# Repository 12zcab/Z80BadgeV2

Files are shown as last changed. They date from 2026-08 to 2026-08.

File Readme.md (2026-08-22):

# Z80 Badge V2

## a total redesign of my fallout badge!

## submitted to Gadget@HackClub

# HUGE THXXXX to Cyao and Acon and mpk for suggestions!!!!

### Images

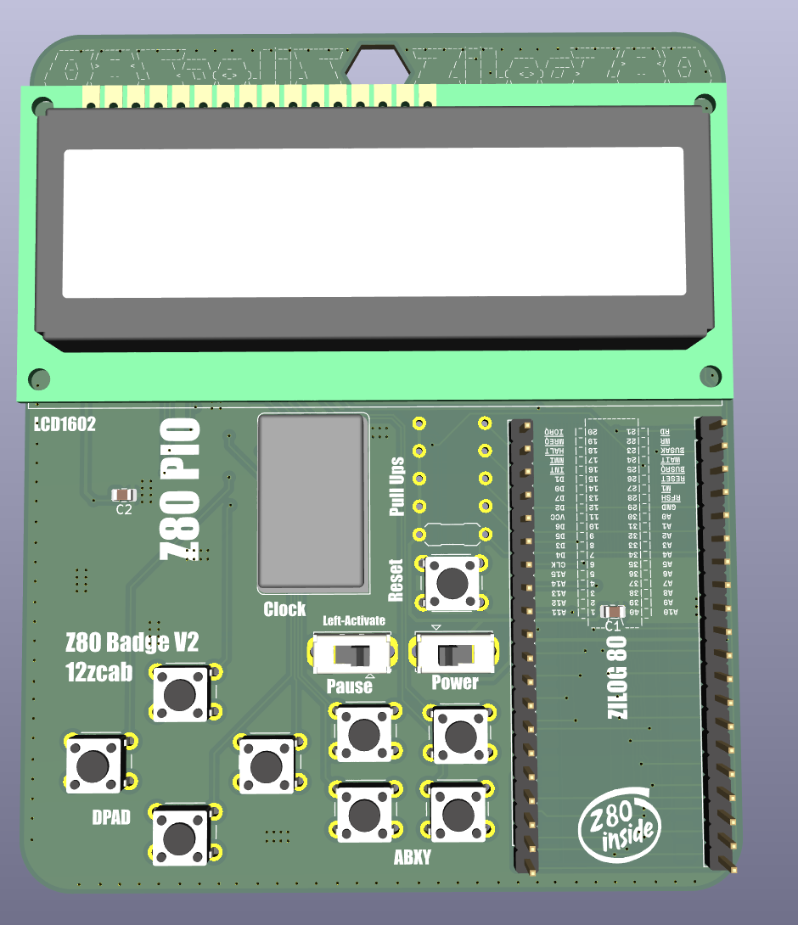
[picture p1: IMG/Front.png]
Front


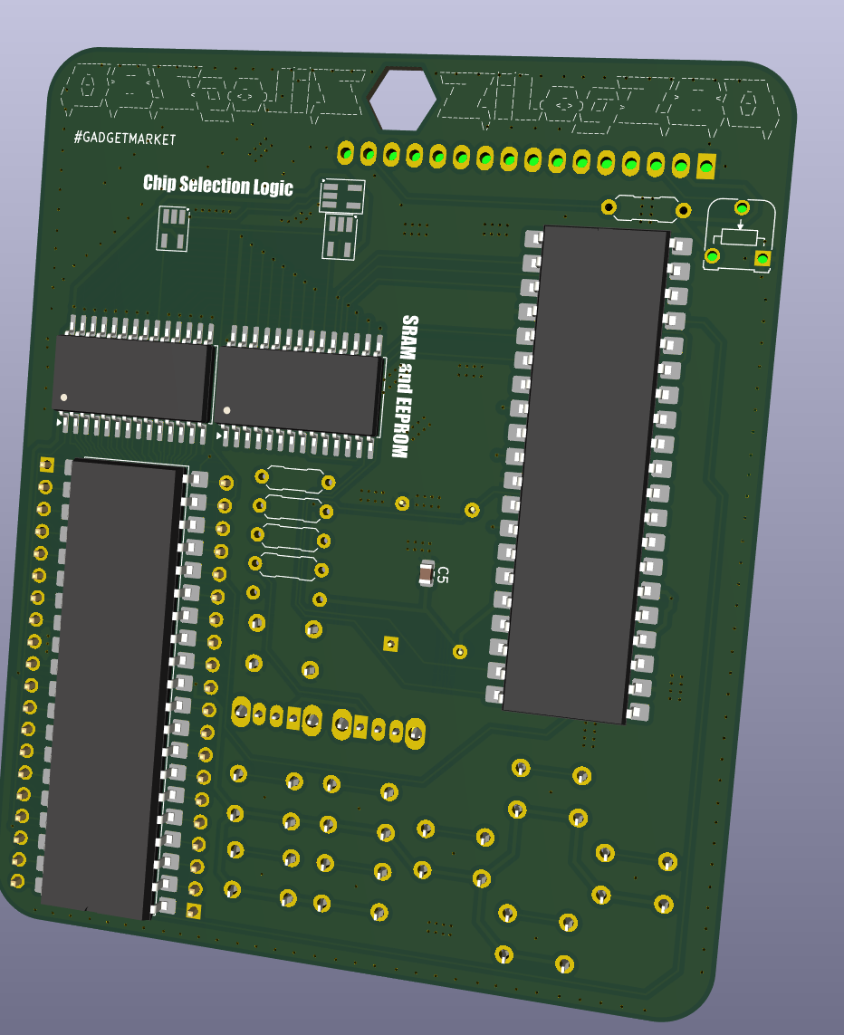
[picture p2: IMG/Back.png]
Back


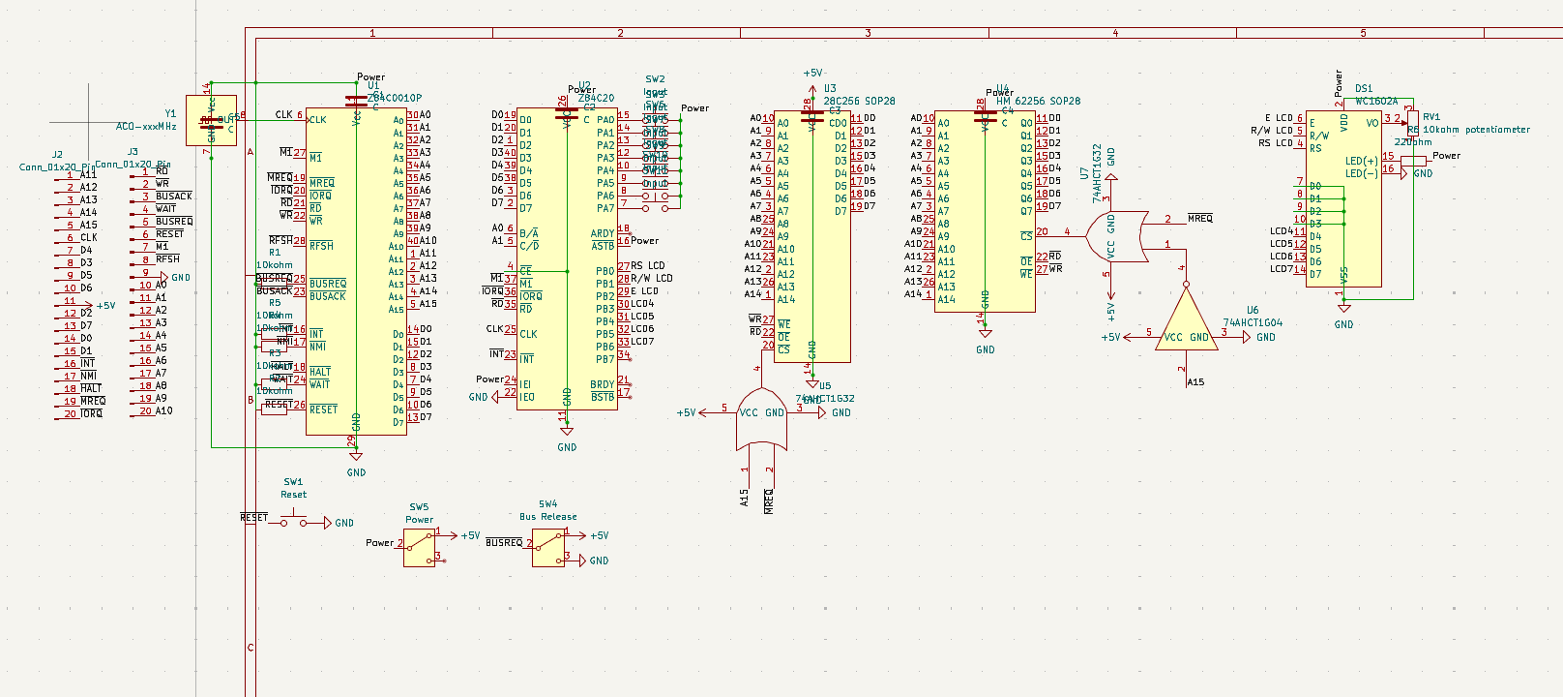
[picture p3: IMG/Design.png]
Design


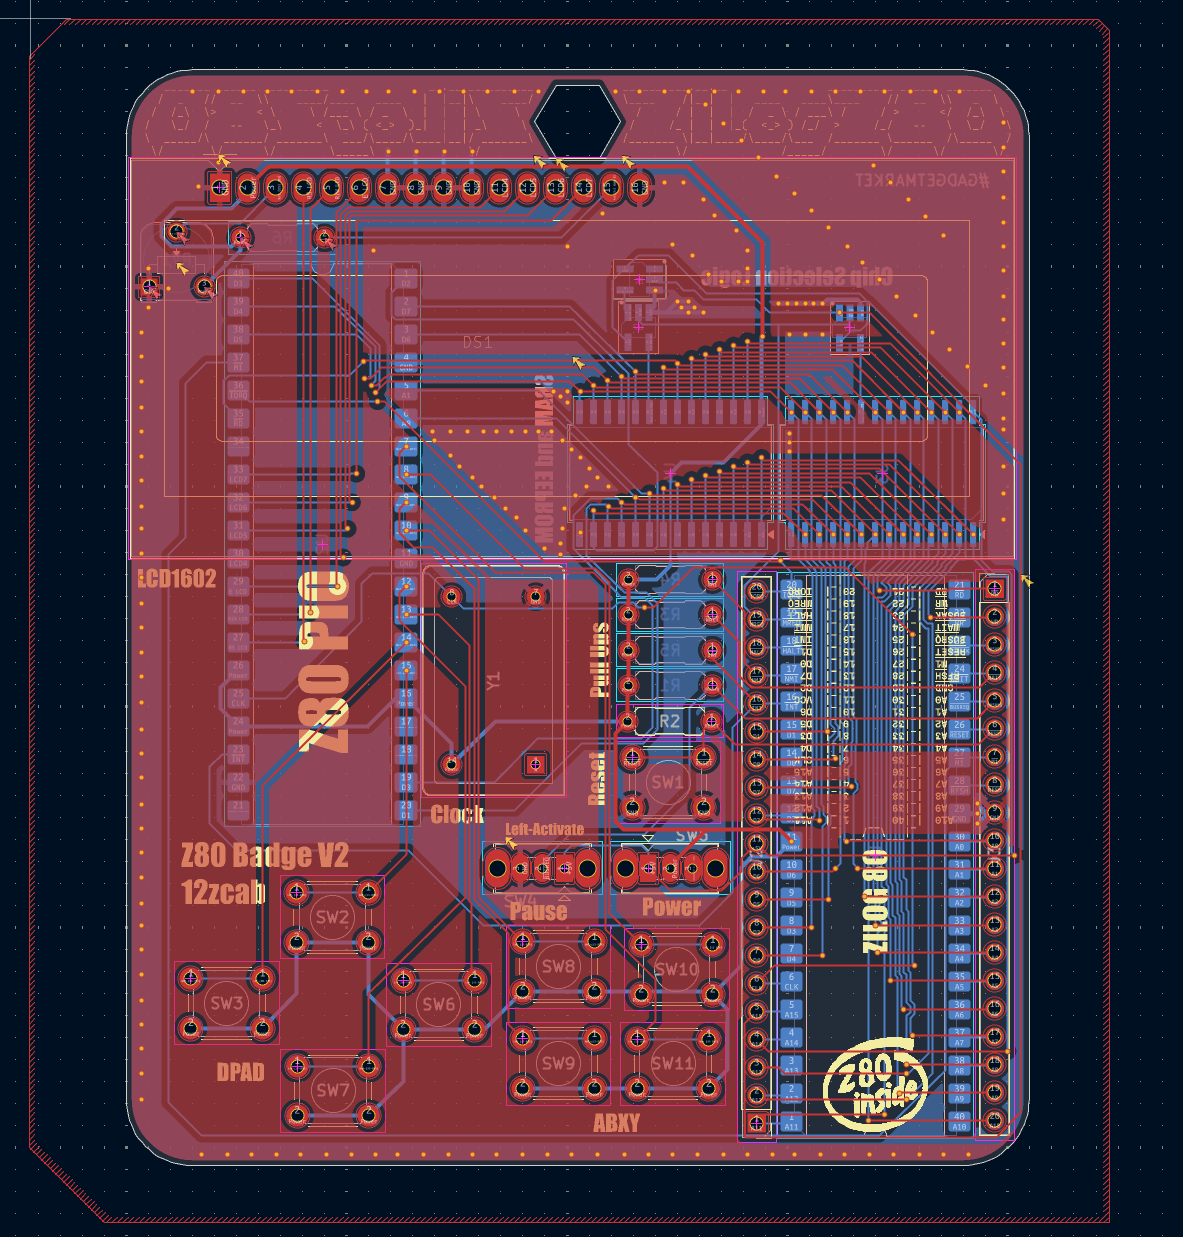
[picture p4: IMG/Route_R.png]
Route


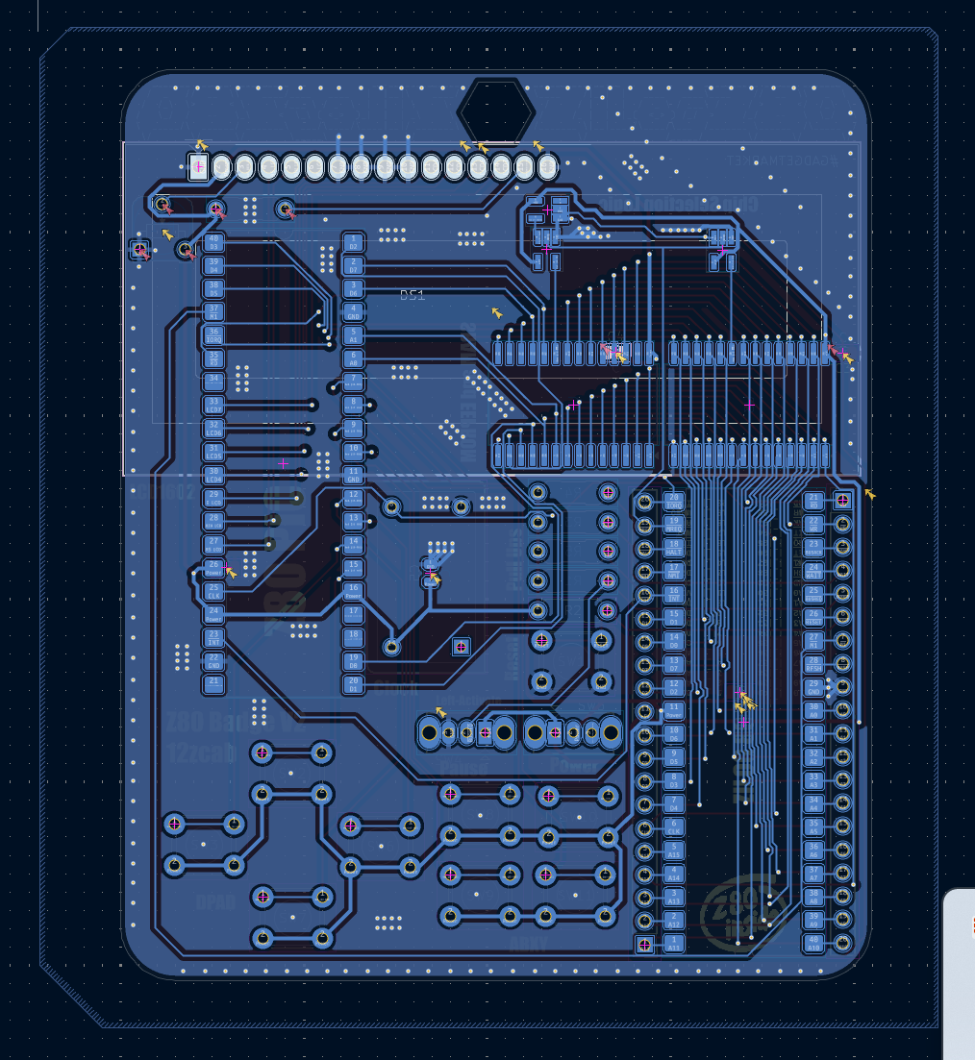
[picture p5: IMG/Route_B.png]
Route


### What is this?

its a small Z80 Computer with 32kByte of EEPROM and 32kByte of SRAM.
it have a minimum setup with practical IO components like LCD1602 and Buttons

Programming this device require you to burn a custom-OS of it or use Dupont Wire to connect its IO PinHeaders to a EEPROM programmer while pausing the whole device and power off.

### How to solder it?

1. Solder EEPROM and SRAM and Chip Select Logics also the 104 capacitors with Reflow or Manual Soldering.
2. Bent the socket's pins and Solder DIP40 Socket and All Resistors.
3. Solder switches and all Buttons and the Crystal OSC.
4. Solder the IO Pin Headers if u want!
5. Solder the 1602 LCD and Plug in all the ICs.
6. Solder the Battery Module and Stick it onto the back of Z80 PIO IC if u need it, Otherwise u can just power with Dupont Wires connecting to the Pin Headers
7. Solder the Battery and Stick it onto the back of Z80 CPU IC if u need it

for BOM details please refer to BOM.csv.

Feel free to open a Issue on GitHub or DM HackClub Slack @12zcab.

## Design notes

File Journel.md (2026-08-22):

[https://hackatime.hackclub.com/my/projects/z80badgev2

Day 1 Z80 Badge V2 10/8/2026
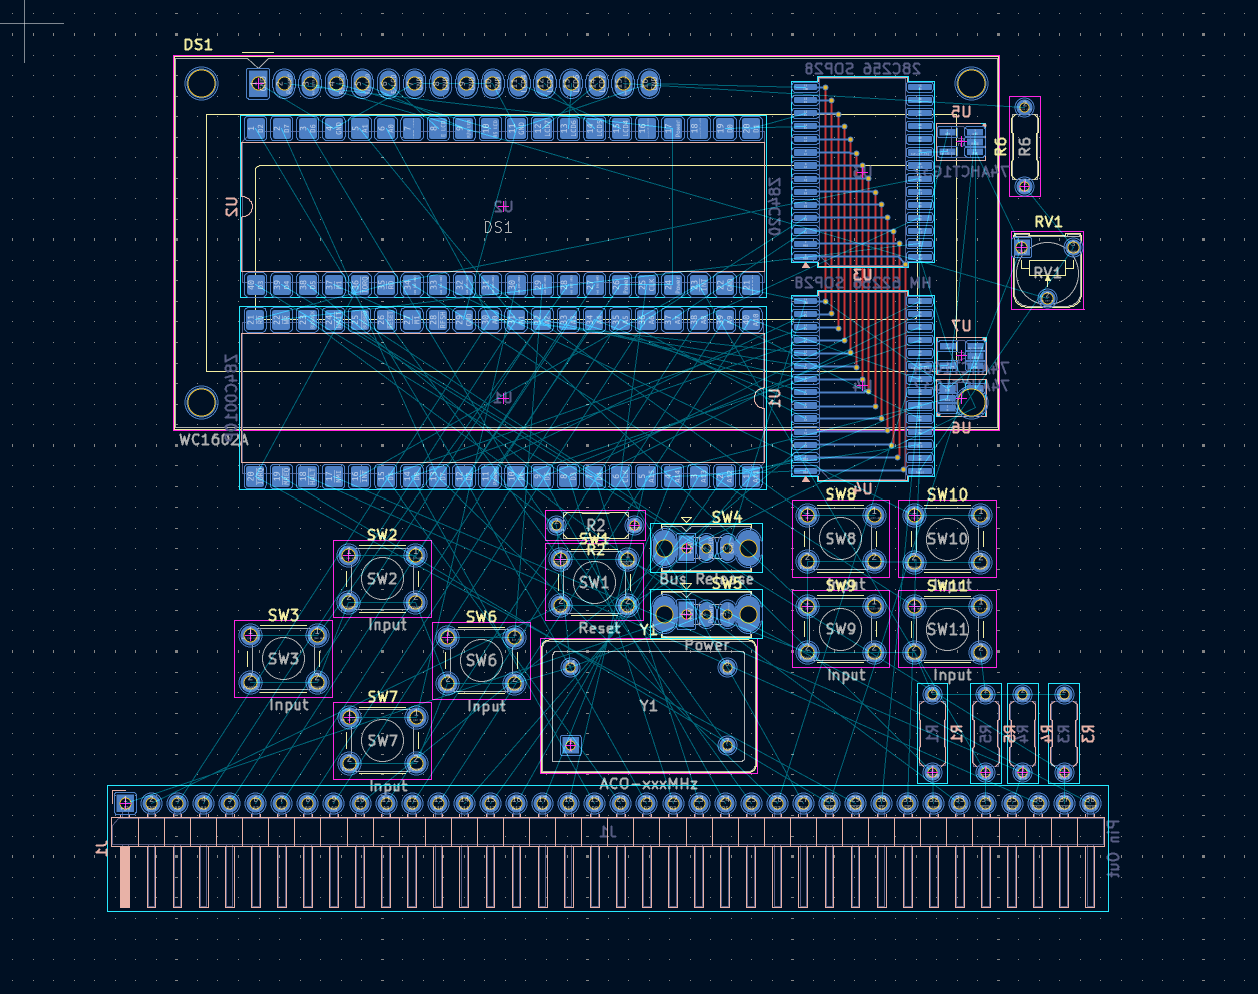
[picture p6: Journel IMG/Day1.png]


lapses:

Z80 Badge 2.0 10/8/2026 (FU5W78anlhWe)

1h 14m

Day 1 Z80 Badge 2.0 (sk8yRzNYfhxx)

45m

Total: 2hrs

yay a new proj for gadget@hackclub :D

so yah my plan is to redesign a small badge at low cost base on the experience i gain from previous failure :|

I started to plan for ICs i need and also searched for packages for components and also planned for functions

im sorry i wrote nothing after this passage in day 1 so the other journals are some descriptions of lapse ihv recorded.

so i searched for components on Taobao and used SMD version of 62256 and 28C256.

Z80 and Z80 PIO are avail. only in DIP package so yah i dont wanna do plcc nor qfn.

so i searched and found theres a thing called SMDIP method so that we can bent dip package's legs and then solder it as a SMD component.

Aimed for lowest cost possible,i used 1602 LCD,Z80 and Z80 PIO also EEPROM and SRAM as my only main components.

I also opened 2.54 PinHeaders for Dupont wires so that i can directly write program on eeprom without using zif sockets for eeprom that is really really large.

Then i quickly choose suitable package for the ICs and try layout them in PCB design but feels not really satisfied for it so i ended today's lapse

Day 2 Z80 Badge V2  11/8/2026
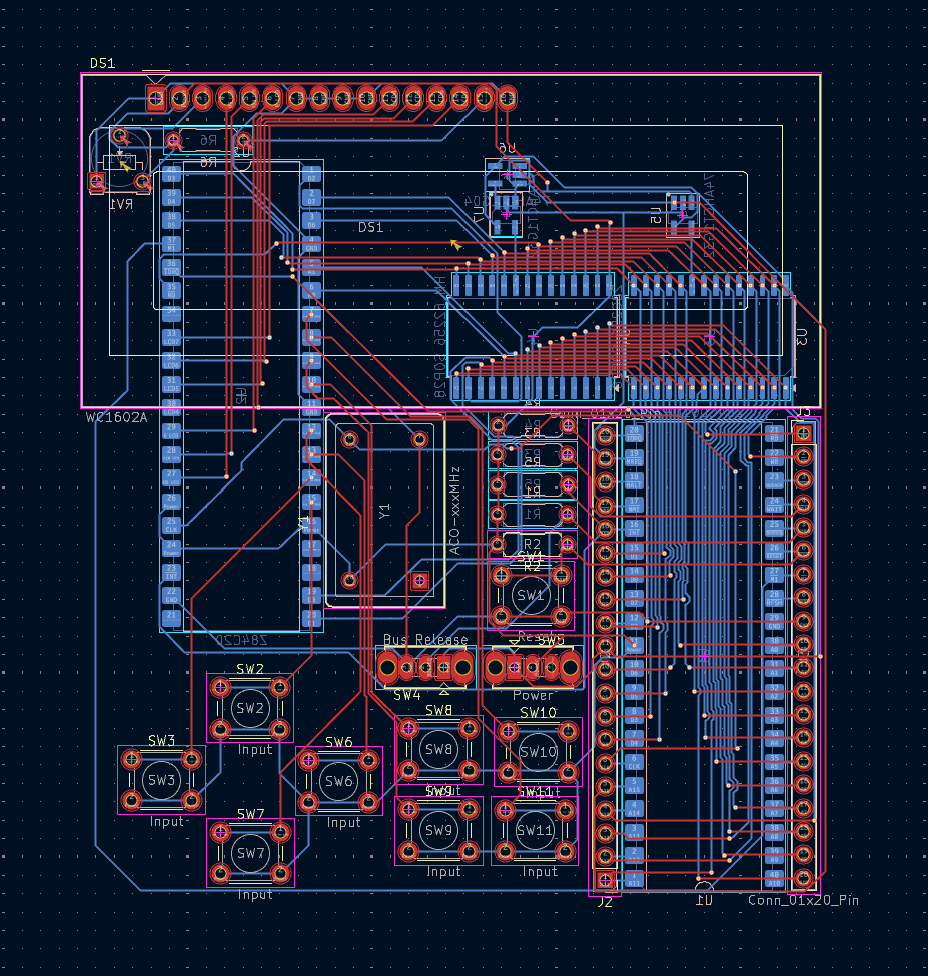
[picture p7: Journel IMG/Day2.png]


lapse:

Z80 Badge 2.0 11/8/2026 (txopF1eqykIc)

1h 42m

Total: 1hr 45mins

So i redesigned the whole layout and finally get something that im satisfied with

then i started to route the whole pcb.

i started with the EEPROM and SRAM part cuz data bus and address bus are the most annoying stuff for this pcb design.

then i routed all the data bus and address bus into a single bus and used a erm Vertical-Horizontal-Dual-Layer routing (idk what thats called) so like basically u mainly use 1 layer of pcb to do 1 direction of routing.

this routing method helped reduce the difficulty while u route address and data bus that its order is not the same.

Day 3 Z80 Badge V2 14/8/2026
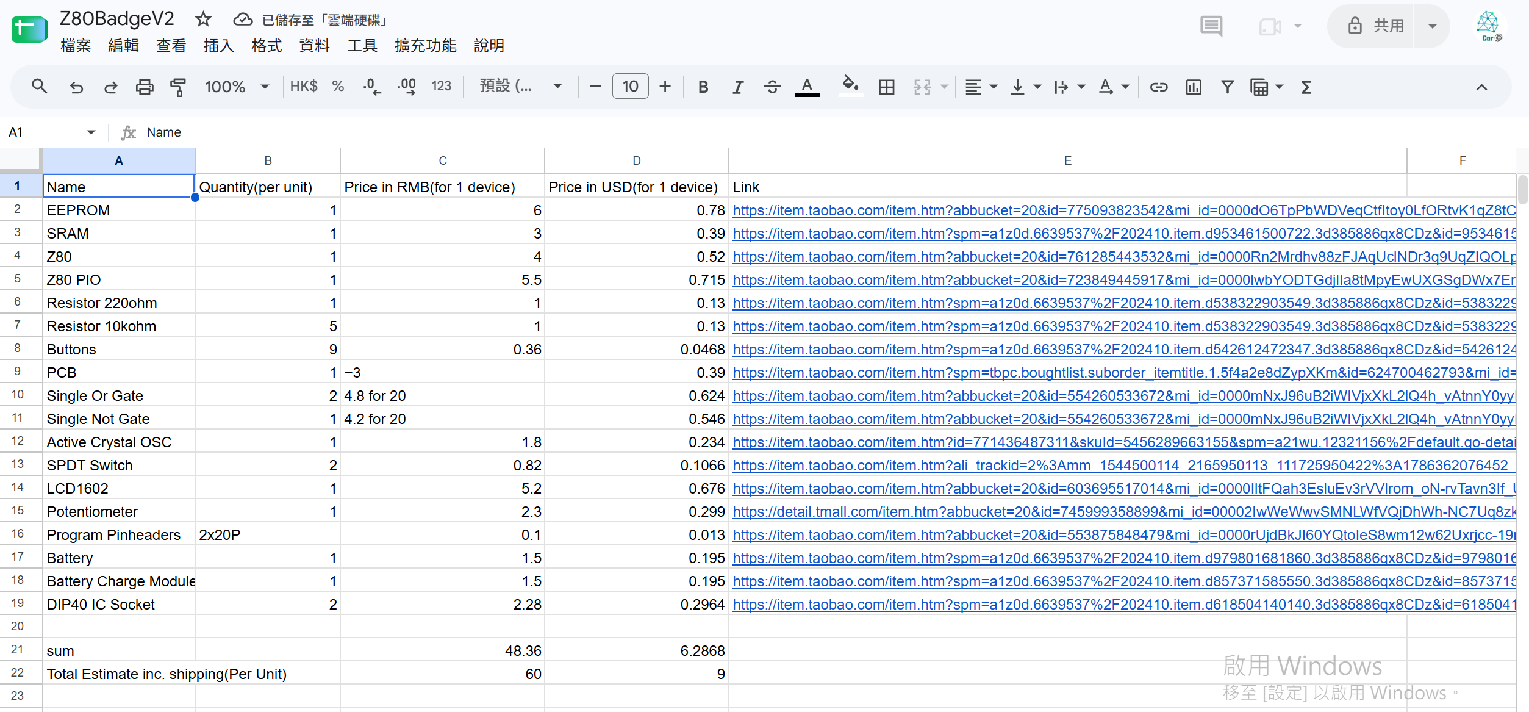
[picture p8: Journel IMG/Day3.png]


lapse:

Day 3 14/8/2026 Z80BadgeV2 (lA8LdgRuLn9C)

Total: 1hr 30mins

yay its almost finished!

i rounded the corner of the PCB and then rerun the drc test and organized the lapses and write this journel lol.

erm yah cuz this pcb is almost full of components i dont really wanna put silkart on it but i added some text on it with my fav. font (IMPACTTTTT)

so the next step is to make a proper BOM.csv and estimate the cost needed to make 5 of it.

Then I Finished the Readme and lets upload to gadget-market-ship!

(but i hope i can make 10 of it if i can :|)

Day4 Z80 Badge V2 15/8/2026
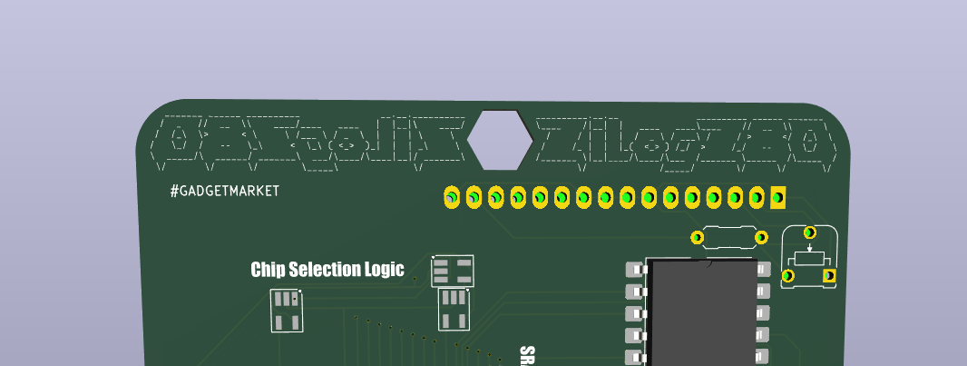
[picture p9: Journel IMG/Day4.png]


lapse:

Day 4 Z80 Badge V2 (70dFCbkBK82y)

1h 3m

Total: 1hr

Added Silkscreen Ascii Art and also 3 holes on the upper side to support different lanyards :D

Day5 Z80 Badge V2 19/8/2026
journalpic

lapse:

Total: 1hr 30min

so today im gonna thicken the power routings.

and also add ground pour, and smaller the hole for lanyard

erm so yah this is da first time i do ground pour design and drc now hv no error popup so i assume its already a usable design...? XD

](https://hackatime.hackclub.com/my/projects/z80badgev2

Day 1 Z80 Badge V2 10/8/2026
journalpic

lapses:

Z80 Badge 2.0 10/8/2026 (FU5W78anlhWe)

1h 14m

Day 1 Z80 Badge 2.0 (sk8yRzNYfhxx)

45m

Total: 2hrs

yay a new proj for gadget@hackclub :D

so yah my plan is to redesign a small badge at low cost base on the experience i gain from previous failure :|

I started to plan for ICs i need and also searched for packages for components and also planned for functions

im sorry i wrote nothing after this passage in day 1 so the other journals are some descriptions of lapse ihv recorded.

so i searched for components on Taobao and used SMD version of 62256 and 28C256.

Z80 and Z80 PIO are avail. only in DIP package so yah i dont wanna do plcc nor qfn.

so i searched and found theres a thing called SMDIP method so that we can bent dip package's legs and then solder it as a SMD component.

Aimed for lowest cost possible,i used 1602 LCD,Z80 and Z80 PIO also EEPROM and SRAM as my only main components.

I also opened 2.54 PinHeaders for Dupont wires so that i can directly write program on eeprom without using zif sockets for eeprom that is really really large.

Then i quickly choose suitable package for the ICs and try layout them in PCB design but feels not really satisfied for it so i ended today's lapse

Day 2 Z80 Badge V2  11/8/2026
journalpic

lapse:

Z80 Badge 2.0 11/8/2026 (txopF1eqykIc)

1h 42m

Total: 1hr 45mins

So i redesigned the whole layout and finally get something that im satisfied with

then i started to route the whole pcb.

i started with the EEPROM and SRAM part cuz data bus and address bus are the most annoying stuff for this pcb design.

then i routed all the data bus and address bus into a single bus and used a erm Vertical-Horizontal-Dual-Layer routing (idk what thats called) so like basically u mainly use 1 layer of pcb to do 1 direction of routing.

this routing method helped reduce the difficulty while u route address and data bus that its order is not the same.

Day 3 Z80 Badge V2 14/8/2026
journalpic

lapse:

Day 3 14/8/2026 Z80BadgeV2 (lA8LdgRuLn9C)

Total: 1hr 30mins

yay its almost finished!

i rounded the corner of the PCB and then rerun the drc test and organized the lapses and write this journel lol.

erm yah cuz this pcb is almost full of components i dont really wanna put silkart on it but i added some text on it with my fav. font (IMPACTTTTT)

so the next step is to make a proper BOM.csv and estimate the cost needed to make 5 of it.

Then I Finished the Readme and lets upload to gadget-market-ship!

(but i hope i can make 10 of it if i can :|)

Day4 Z80 Badge V2 15/8/2026
journalpic

lapse:

Day 4 Z80 Badge V2 (70dFCbkBK82y)

1h 3m

Total: 1hr

Added Silkscreen Ascii Art and also 3 holes on the upper side to support different lanyards :D

Day5 Z80 Badge V2 19/8/2026
journalpic

lapse:GROUND POURRINNGNGGG (Day5 Z80badgeV2 (Tuy3TwwTRu_g)
Total: 1hr 30min

so today im gonna thicken the power routings.

and also add ground pour, and smaller the hole for lanyard

erm so yah this is da first time i do ground pour design and drc now hv no error popup so i assume its already a usable design...? XD

Day6 Z80 Badge V2 22/8/2026
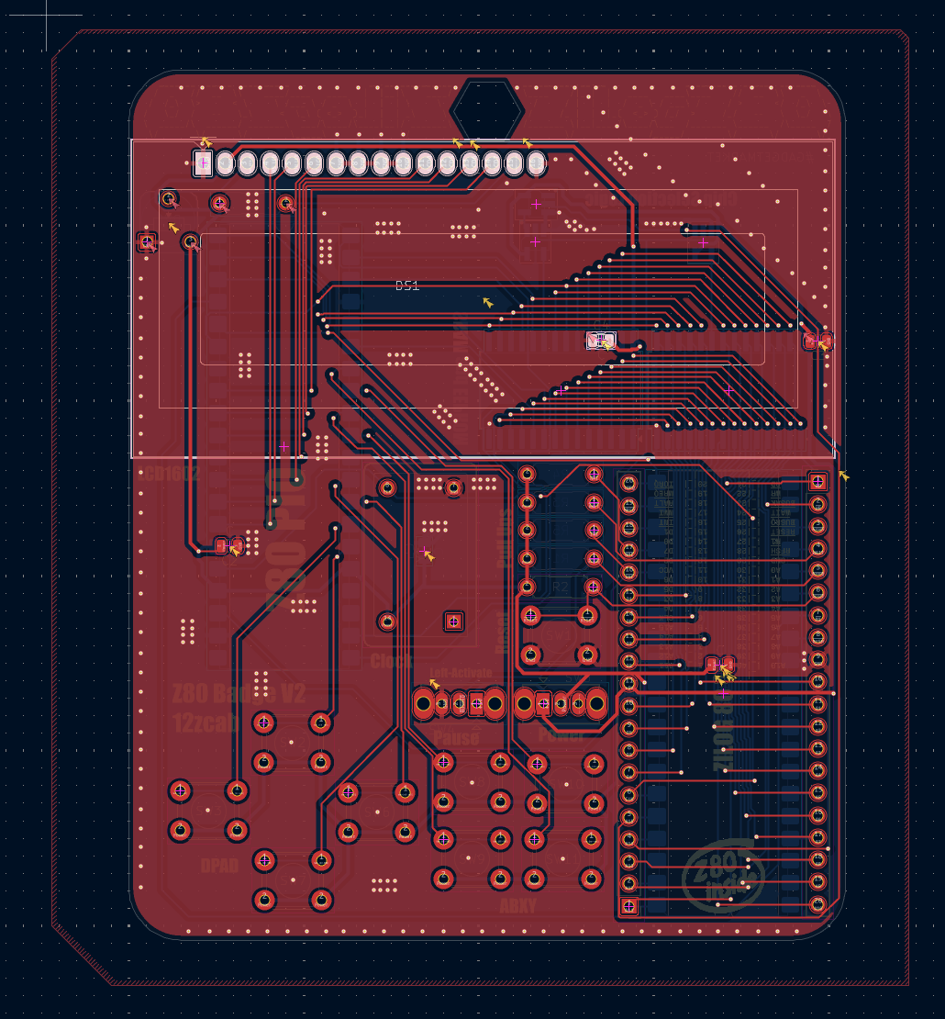
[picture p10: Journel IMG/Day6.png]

lapse:Day6 Z80BadgeV2 (fp8f03s_dZGP)
Total:1h 28m

Increase Gap between bus traces
Added decoupling capacitors
moved vias out of the pads)

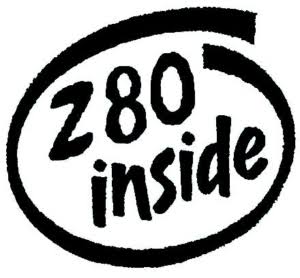
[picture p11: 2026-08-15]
images.jpg

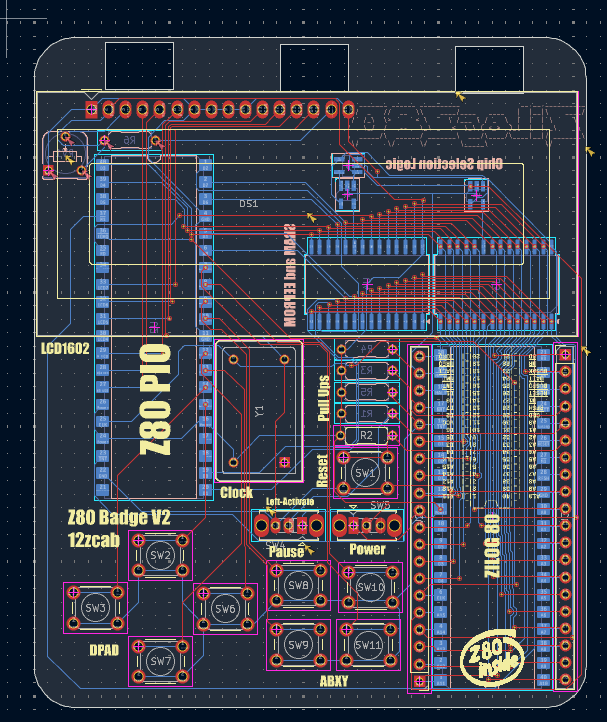
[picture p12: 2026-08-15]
IMG/Route.png

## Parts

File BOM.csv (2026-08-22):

Name | Quantity(per unit) | Price in RMB(for 1 device) | Price in USD(for 1 device) | Link
EEPROM | 1 | 6 | 0.78 | https://item.taobao.com/item.htm?id=775093823542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
SRAM | 1 | 3 | 0.39 | https://item.taobao.com/item.htm?id=953461500722&from=cart&upStreamPrice=300
Z80 | 1 | 4 | 0.52 | https://item.taobao.com/item.htm?id=761285443532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
Z80 PIO | 1 | 5.5 | 0.715 | https://item.taobao.com/item.htm?id=723849445917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
Resistor 220ohm | 1 | 1 | 0.13 | https://item.taobao.com/item.htm?id=538322903549&from=cart&upStreamPrice=100
Resistor 10kohm | 5 | 1 | 0.13 | https://item.taobao.com/item.htm?id=538322903549&from=cart&upStreamPrice=100
Buttons | 9 | 0.36 | 0.0468 | https://item.taobao.com/item.htm?id=542612472347&from=cart&upStreamPrice=4
PCB | 1 | ~3 | 0.39 | https://item.taobao.com/item.htm?id=624700462793
Single Or Gate | 2 | 4.8 for 20 | 0.624 | https://item.taobao.com/item.htm?id=554260533672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
Single Not Gate | 1 | 4.2 for 20 | 0.546 | https://item.taobao.com/item.htm?id=554260533672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
Active Crystal OSC | 1 | 1.8 | 0.234 | https://item.taobao.com/item.htm?id=771436487311&skuId=5456289663155
SPDT Switch | 2 | 0.82 | 0.1066 | https://item.taobao.com/item.htm?id=568771505825
LCD1602 | 1 | 5.2 | 0.676 | https://item.taobao.com/item.htm?id=603695517014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
Potentiometer | 1 | 2.3 | 0.299 | https://detail.tmall.com/item.htm?id=745999358899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
Program Pinheaders | 2x20P | 0.1 | 0.013 | https://item.taobao.com/item.htm?abbucket=20&id=553875848479&ns=1&skuId=6138476482167&xxc=taobaoSearch
Battery | 1 | 1.5 | 0.195 | https://item.taobao.com/item.htm?id=979801681860&from=cart&skuId=6101299806844&upStreamPrice=150
Battery Charge Module | 1 | 1.5 | 0.195 | https://item.taobao.com/item.htm?id=857371585550&from=cart&skuId=5832395418380&upStreamPrice=150
DIP40 IC Socket | 2 | 2.28 | 0.2964 | https://item.taobao.com/item.htm?id=618504140140&from=cart&skuId=4371738857383&upStreamPrice=228
104 Capacitor | 5 | 0.2 | 0.03 | https://item.taobao.com/item.htm?id=679031412640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
sum |  | 48.36 | 6.3168
Total Estimate inc. shipping(Per Unit) |  | 60 | 9

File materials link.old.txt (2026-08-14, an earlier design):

DONT BUY THESE LINKS THESE ARE ONLY FOR DESIGN NOTES

Battery Charge
https://item.taobao.com/item.htm?id=857371585550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
Battery
https://item.taobao.com/item.htm?id=979801681860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

CPU and PIO
https://item.taobao.com/item.htm?id=761285443532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
https://item.taobao.com/item.htm?id=723849445917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

LCD
https://item.taobao.com/item.htm?id=603695517014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

SRAM
https://item.taobao.com/item.htm?id=953461500722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

EEPROM
https://item.taobao.com/item.htm?id=775093823542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

PinHeaders
https://item.taobao.com/item.htm?id=574397863780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

OSC crystal
https://item.taobao.com/item.htm?id=771436487311&skuId=5456289663155&spm=a21wu.12321156%2Fdefault.go-detail.1

6mm buttons
https://item.taobao.com/item.htm?id=542612472347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

SS12D00G3_3脚2档_插件(10只)
https://item.taobao.com/item.htm?id=568771505825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

10kohm resis
https://item.taobao.com/item.htm?id=538322903549&spm=a21wu.12321156-tw%2Fdefault.go-detail.1

DIP40
https://detail.tmall.com/item.htm?id=618504140140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

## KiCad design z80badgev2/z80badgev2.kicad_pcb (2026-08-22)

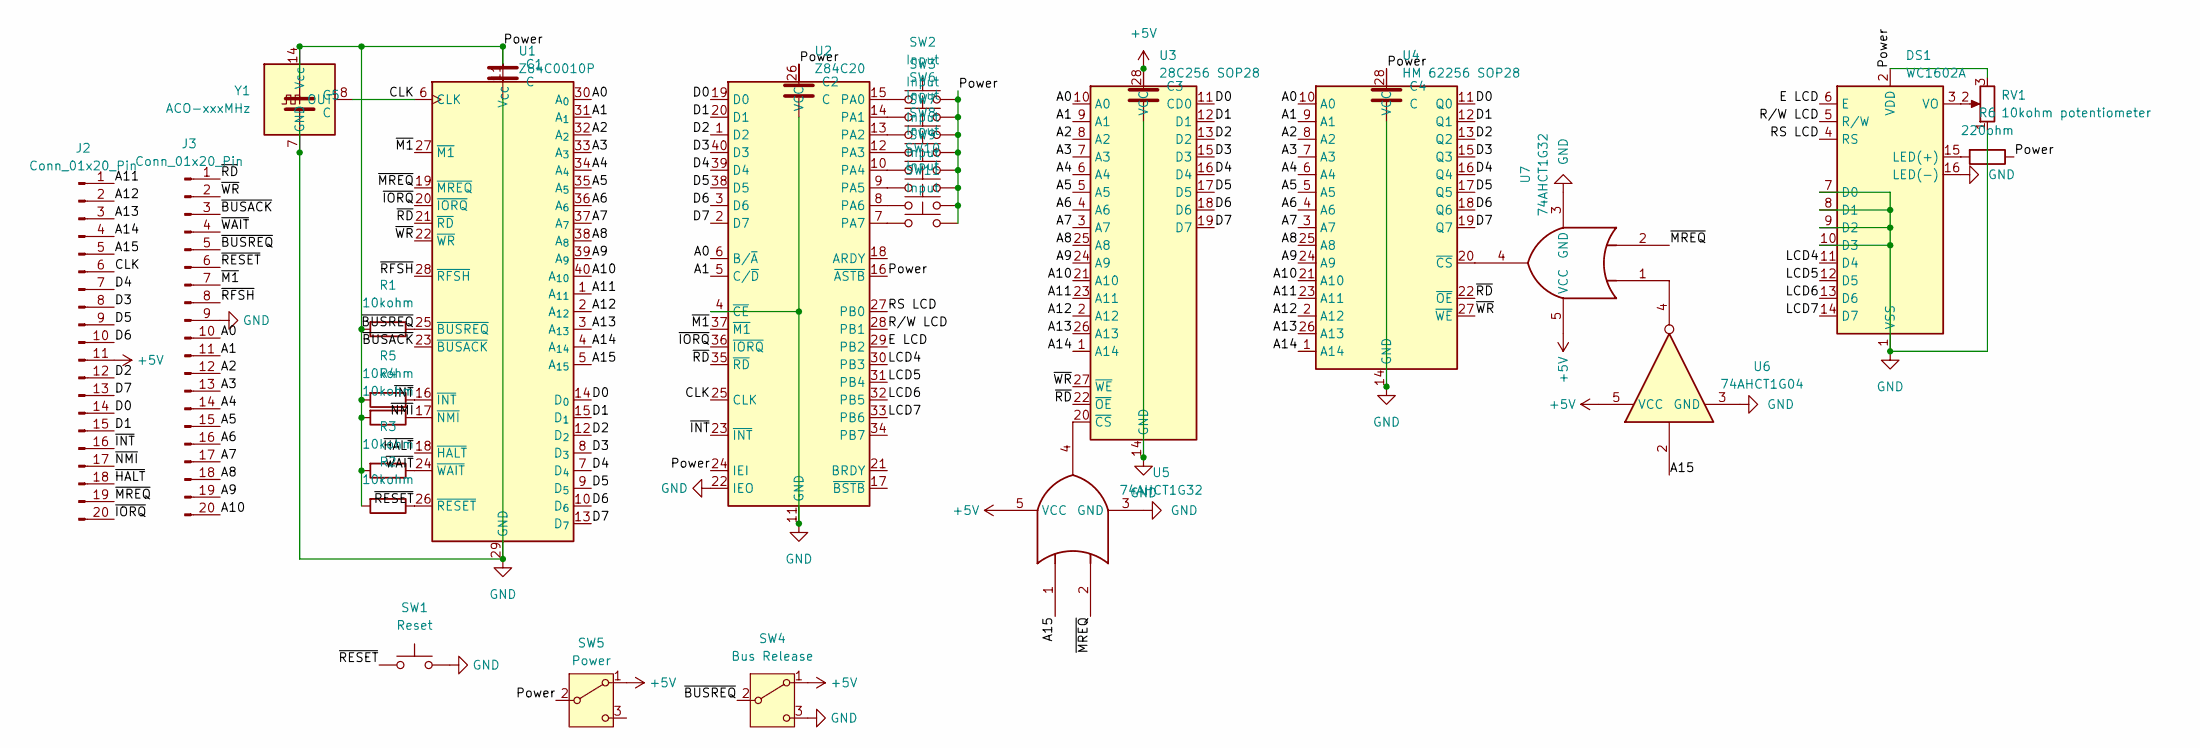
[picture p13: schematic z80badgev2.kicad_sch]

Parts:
C1, C2, C3, C4, C5: C; C_0805_2012Metric
DS1: WC1602A
J2, J3: Conn_01x20_Pin; PinHeader_1x20_P2.54mm_Vertical
R1, R2, R3, R4, R5: 10kohm; R_Axial_DIN0207_L6.3mm_D2.5mm_P7.62mm_Horizontal
R6: 220ohm; R_Axial_DIN0207_L6.3mm_D2.5mm_P7.62mm_Horizontal
RV1: 10kohm potentiometer; Potentiometer_Runtron_RM-065_Vertical
SW1: Reset; SW_PUSH_6mm
SW2, SW3, SW6, SW7, SW8, SW9, SW10, SW11: Input; SW_PUSH_6mm
SW4: Bus Release; SW_Slide_SPDT_Straight_CK_OS102011MS2Q
SW5: Power; SW_Slide_SPDT_Straight_CK_OS102011MS2Q
U1: Z84C0010P; SMDIP-40_W15.24mm
U2: Z84C20; SMDIP-40_W15.24mm
U3: 28C256 SOP28; SOP-28_8.4x18.16mm_P1.27mm
U4: HM 62256 SOP28; SOP-28_8.4x18.16mm_P1.27mm
U5, U7: 74AHCT1G32; SOT-23-5_HandSoldering
U6: 74AHCT1G04; SOT-23-5_HandSoldering
Y1: ACO-xxxMHz; Oscillator_DIP-14

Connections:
+5V: C3.2, J2.11, SW4.1 (A), SW5.1 (A), U3.28 (VCC), U5.5 (VCC), U6.5 (VCC), U7.5 (VCC)
/A0: J3.10, U1.30 (A_{0}), U2.6 (B/~A), U3.10 (A0), U4.10 (A0)
/A1: J3.11, U1.31 (A_{1}), U2.5 (C/~D), U3.9 (A1), U4.9 (A1)
/A2: J3.12, U1.32 (A_{2}), U3.8 (A2), U4.8 (A2)
/A3: J3.13, U1.33 (A_{3}), U3.7 (A3), U4.7 (A3)
/A4: J3.14, U1.34 (A_{4}), U3.6 (A4), U4.6 (A4)
/A5: J3.15, U1.35 (A_{5}), U3.5 (A5), U4.5 (A5)
/A6: J3.16, U1.36 (A_{6}), U3.4 (A6), U4.4 (A6)
/A7: J3.17, U1.37 (A_{7}), U3.3 (A7), U4.3 (A7)
/A8: J3.18, U1.38 (A_{8}), U3.25 (A8), U4.25 (A8)
/A9: J3.19, U1.39 (A_{9}), U3.24 (A9), U4.24 (A9)
/A10: J3.20, U1.40 (A_{10}), U3.21 (A10), U4.21 (A10)
/A11: J2.1, U1.1 (A_{11}), U3.23 (A11), U4.23 (A11)
/A12: J2.2, U1.2 (A_{12}), U3.2 (A12), U4.2 (A12)
/A13: J2.3, U1.3 (A_{13}), U3.26 (A13), U4.26 (A13)
/A14: J2.4, U1.4 (A_{14}), U3.1 (A14), U4.1 (A14)
/A15: J2.5, U1.5 (A_{15}), U5.1, U6.2
/CLK: J2.6, U1.6 (CLK), U2.25 (CLK), Y1.8 (OUT)
/D0: J2.14, U1.14 (D_{0}), U2.19 (D0), U3.11 (D0), U4.11 (Q0)
/D1: J2.15, U1.15 (D_{1}), U2.20 (D1), U3.12 (D1), U4.12 (Q1)
/D2: J2.12, U1.12 (D_{2}), U2.1 (D2), U3.13 (D2), U4.13 (Q2)
/D3: J2.8, U1.8 (D_{3}), U2.40 (D3), U3.15 (D3), U4.15 (Q3)
/D4: J2.7, U1.7 (D_{4}), U2.39 (D4), U3.16 (D4), U4.16 (Q4)
/D5: J2.9, U1.9 (D_{5}), U2.38 (D5), U3.17 (D5), U4.17 (Q5)
/D6: J2.10, U1.10 (D_{6}), U2.3 (D6), U3.18 (D6), U4.18 (Q6)
/D7: J2.13, U1.13 (D_{7}), U2.2 (D7), U3.19 (D7), U4.19 (Q7)
/E LCD: DS1.6 (E), U2.29 (PB2)
/LCD4: DS1.11 (D4), U2.30 (PB3)
/LCD5: DS1.12 (D5), U2.31 (PB4)
/LCD6: DS1.13 (D6), U2.32 (PB5)
/LCD7: DS1.14 (D7), U2.33 (PB6)
/Power: C1.2, C2.2, C4.2, C5.2, DS1.2 (VDD), R1.2, R2.2, R3.2, R4.2, R5.2, R6.1, RV1.3, SW2.2, SW3.2, SW5.2 (B), SW6.2, SW7.2, SW8.2, SW9.2, SW10.2, SW11.2, U1.11 (V_{CC}), U2.16 (~ASTB), U2.24 (IEI), U2.26 (VCC), U4.28 (VCC), Y1.14 (Vcc)
/RS LCD: DS1.4 (RS), U2.27 (PB0)
/R/W LCD: DS1.5 (R/W), U2.28 (PB1)
/~BUSACK: J3.3, U1.23 (~BUSACK)
/~BUSREQ: J3.5, R1.1, SW4.2 (B), U1.25 (~BUSREQ)
/~HALT: J2.18, U1.18 (~HALT)
/~INT: J2.16, R5.1, U1.16 (~INT), U2.23 (~INT)
/~IORQ: J2.20, U1.20 (~IORQ), U2.36 (~IORQ)
/~M1: J3.7, U1.27 (~M1), U2.37 (~M1)
/~MREQ: J2.19, U1.19 (~MREQ), U5.2, U7.2
/~NMI: J2.17, R4.1, U1.17 (~NMI)
/~RD: J3.1, U1.21 (~RD), U2.35 (~RD), U3.22 (~OE), U4.22 (~OE)
/~RESET: J3.6, R2.1, SW1.1, U1.26 (~RESET)
/~RFSH: J3.8, U1.28 (~RFSH)
/~WAIT: J3.4, R3.1, U1.24 (~WAIT)
/~WR: J3.2, U1.22 (~WR), U3.27 (~WE), U4.27 (~WE)
GND: C1.1, C2.1, C3.1, C4.1, C5.1, DS1.1 (VSS), DS1.7 (D0), DS1.8 (D1), DS1.9 (D2), DS1.10 (D3), DS1.16 (LED(-)), J3.9, RV1.1, SW1.2, SW4.3 (C), U1.29 (GND), U2.4 (~CE), U2.11 (GND), U2.22 (IEO), U3.14 (GND), U4.14 (GND), U5.3 (GND), U6.3 (GND), U7.3 (GND), Y1.7 (GND)
unnamed: DS1.15 (LED(+)), R6.2
unnamed: DS1.3 (VO), RV1.2
unnamed: SW2.1, U2.15 (PA0)
unnamed: SW3.1, U2.14 (PA1)
unnamed: SW6.1, U2.13 (PA2)
unnamed: SW7.1, U2.12 (PA3)
unnamed: SW8.1, U2.10 (PA4)
unnamed: SW9.1, U2.9 (PA5)
unnamed: SW10.1, U2.8 (PA6)
unnamed: SW11.1, U2.7 (PA7)
unnamed: U3.20 (~CS), U5.4
unnamed: U4.20 (~CS), U7.4
unnamed: U6.4, U7.1

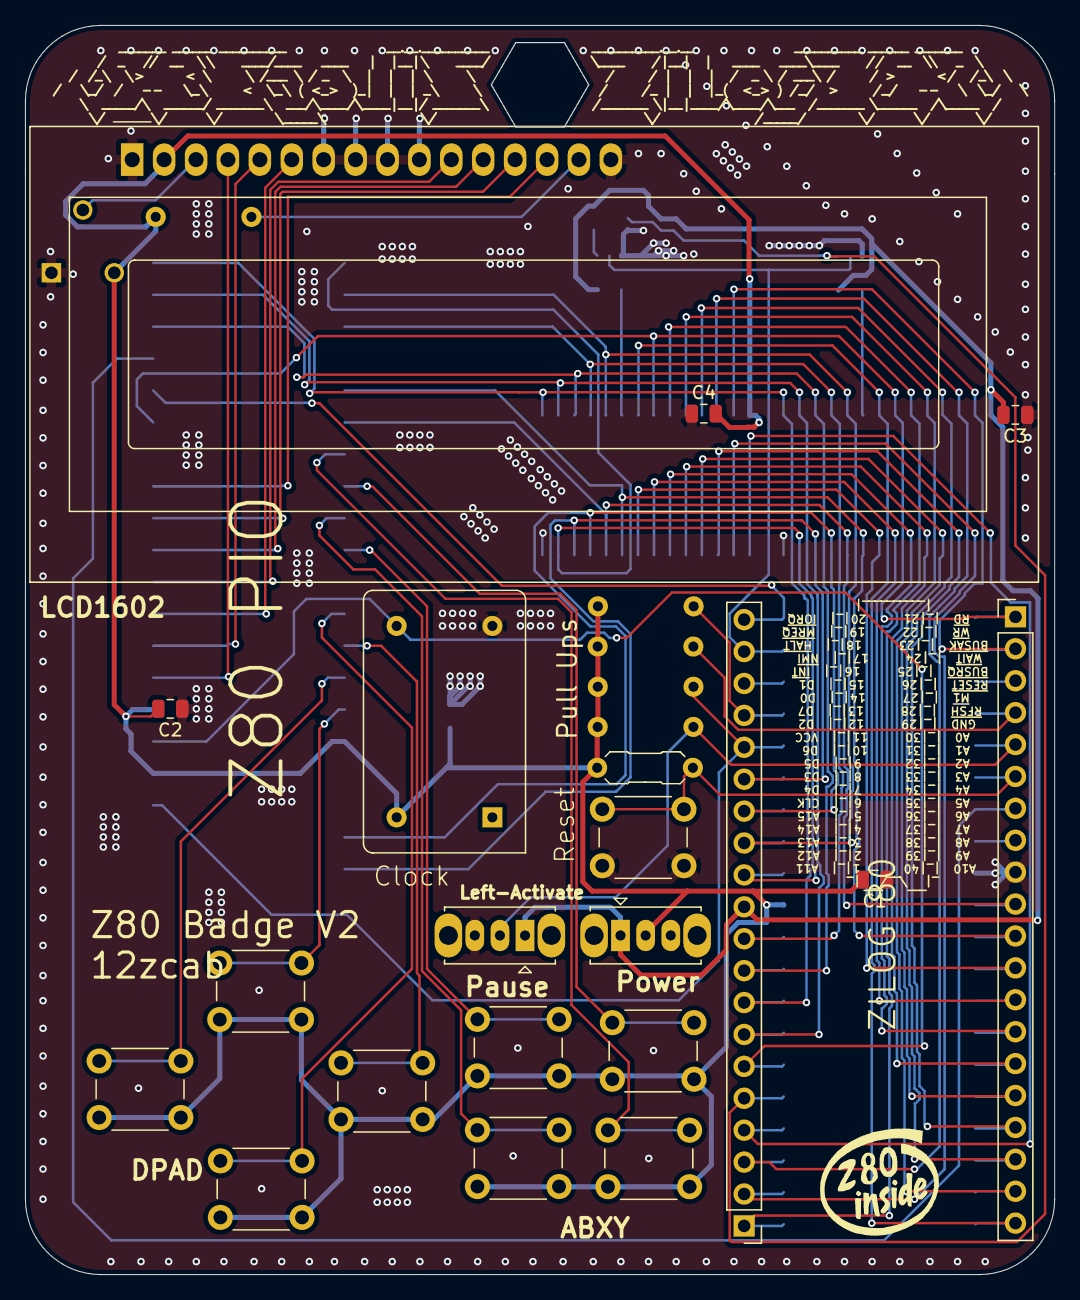
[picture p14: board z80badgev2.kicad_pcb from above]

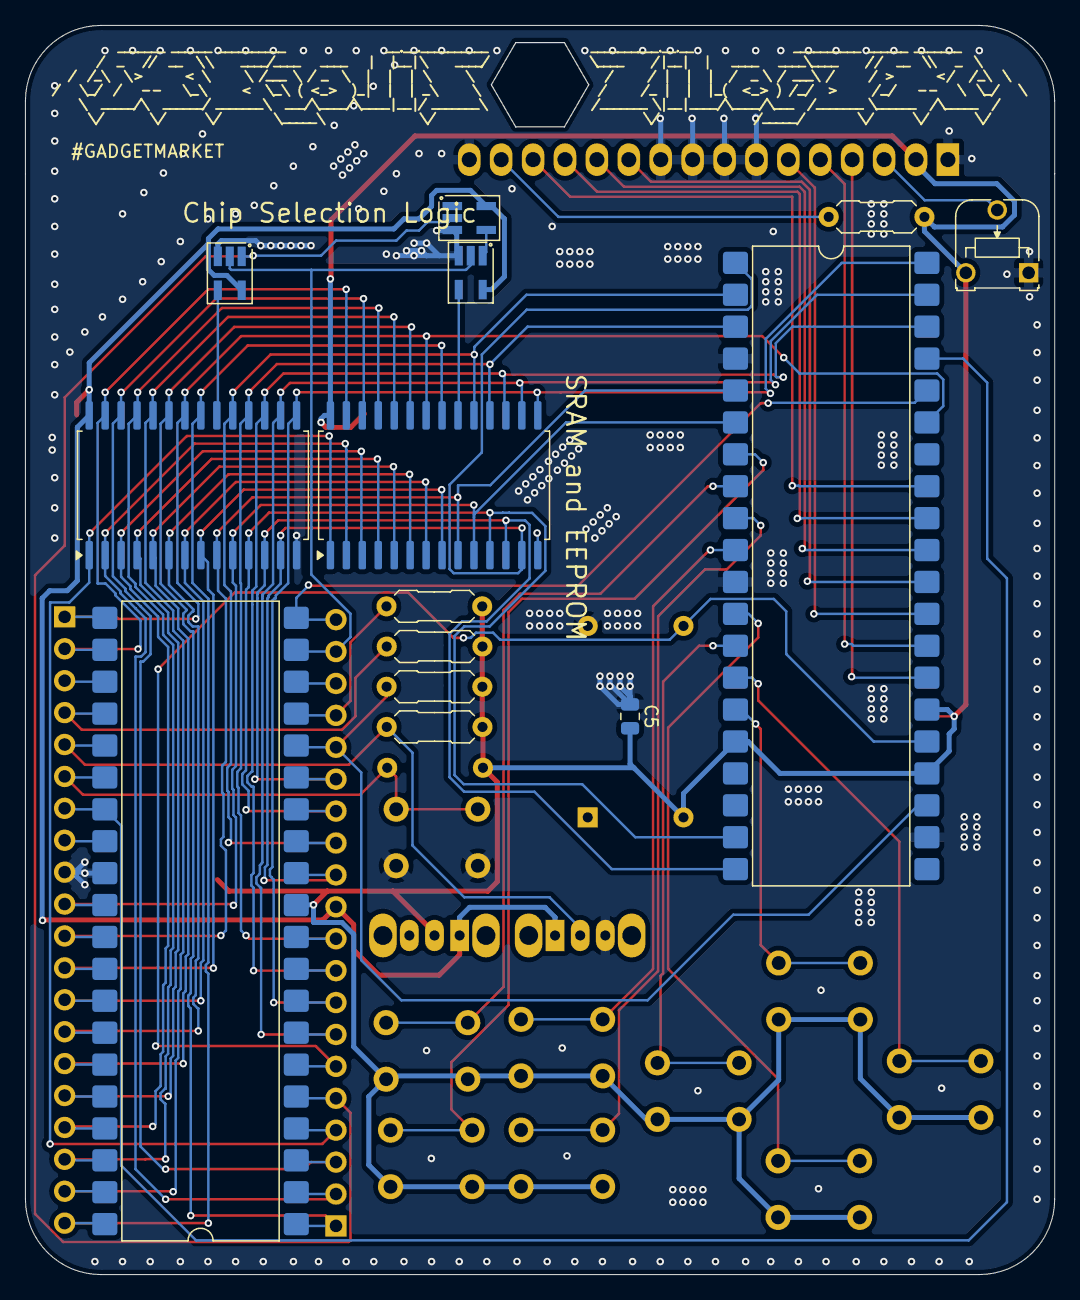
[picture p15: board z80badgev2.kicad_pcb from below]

Board: 2 copper layers, 81.9 x 99.4 mm, 34 parts (14 on the bottom side), 61 nets.
